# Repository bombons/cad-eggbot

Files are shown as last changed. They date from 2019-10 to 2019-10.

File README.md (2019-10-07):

# CAD

# Installazione

Per farlo funzionare serve OBBLIGATORIAMENTE il condensatore per disabilitare l'autoreset, condensatore da 10 µF posizionato su il pin RST GND; questo deve essere tolto ogni volta che si vuole reflashare la board

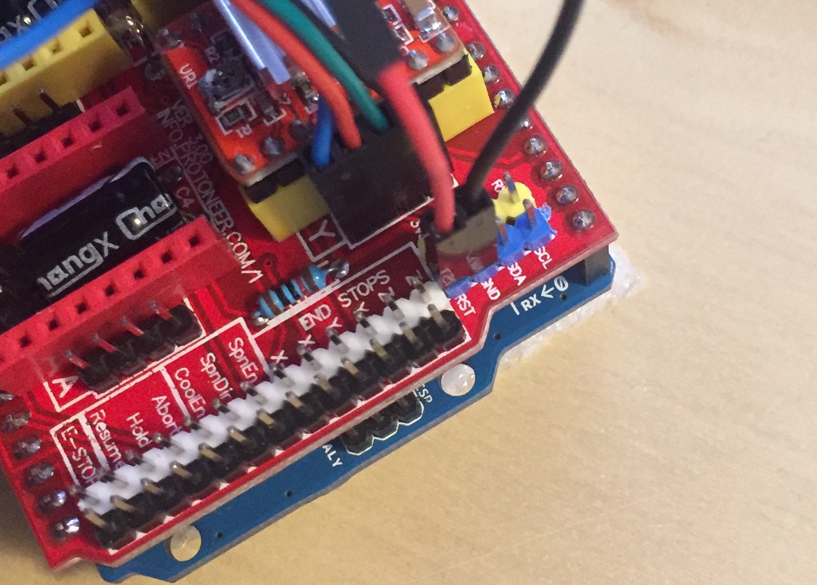
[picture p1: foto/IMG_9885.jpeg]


I motori girano giusti se mantengono questo ordine di fili dal basso verso l'alto (B)(R)(G)(BK)

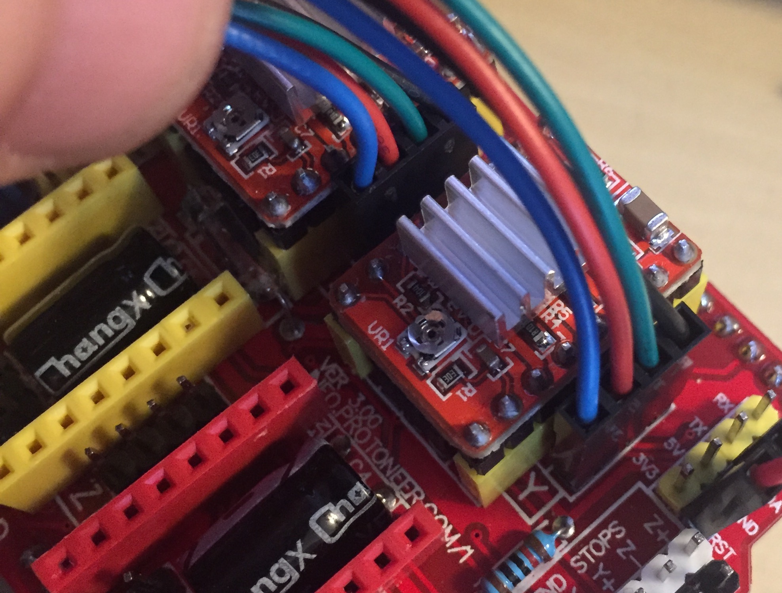
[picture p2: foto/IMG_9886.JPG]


Per il servo motore invece ho usato la posizione dei pin indicata nel firmware che è questa MARRONE->GND ROSSO->5V ARANCIO->Z.STEP

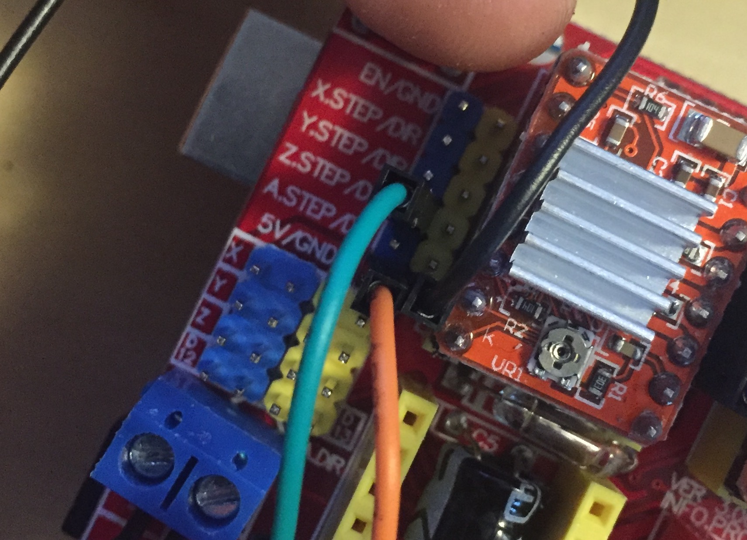
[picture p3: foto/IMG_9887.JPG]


# Firmware

Usata la fork di plex3r, volendo ha anche dei file da sostituire se il plugin su inkscape non funzionasse, però a me è andato senza problemi

[EggDuiono_plex3r](./firmware/EggDuino_plex3r)

# Estensione

Installa Inkscape

```bash
brew cask install InkScape
```

Poi installa l'estensione da [EggBot_v2.5.0_Mac.dmg](./firmware/EggBot_v2.5.0_Mac.dmg)

Dentro ci sono anche dei file di esempio

# TODO

<!-- - [x] per mettere il tik -->
- [ ] mettere switch per permettere di flashare senza togliere il condensatore
- [ ] ricontrolla come si calcola la VREF perchè cristian dice che quella spiegazione era un pochino errata ma in così per ora funzione ed è molto bassa
- [x] il cuscinetto sul filetto non si può vedere
- [x] migliorare il porta cuscinetto
- [x] soluzione più stabile del pezzo che porta la barra filettata
- [x] dove si inseriscono le barre metti delle viti per bloccare saldamente la barra
- [x] i fori stampati risultano leggermente troppo grandi in tutte le parti forse è un errore di stampa mio ma controlla sul file originale
- [x] al portapenna, cambia posizione del blocca penna e metti un pomellino

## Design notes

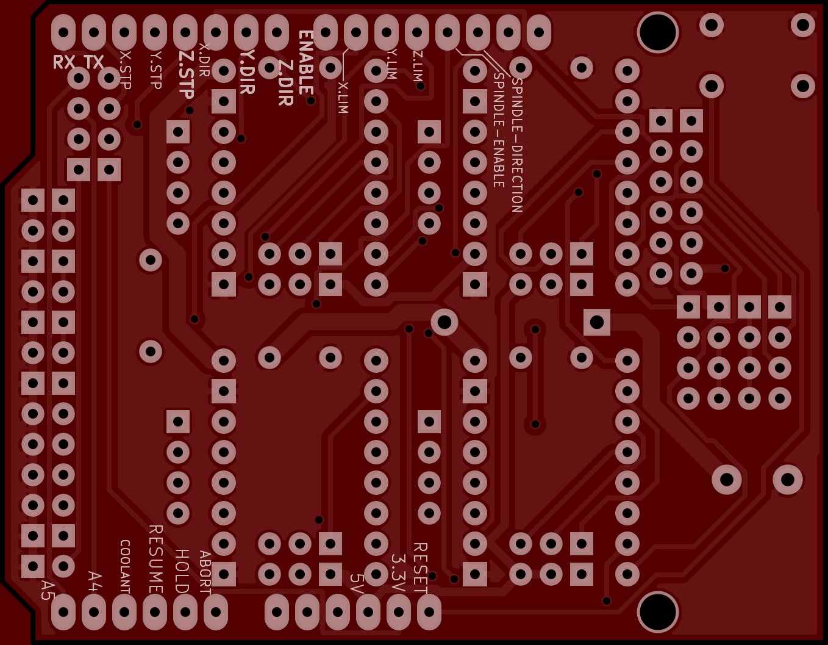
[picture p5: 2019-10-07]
progetto/035d4acb351dea535adb94660df1c265.png

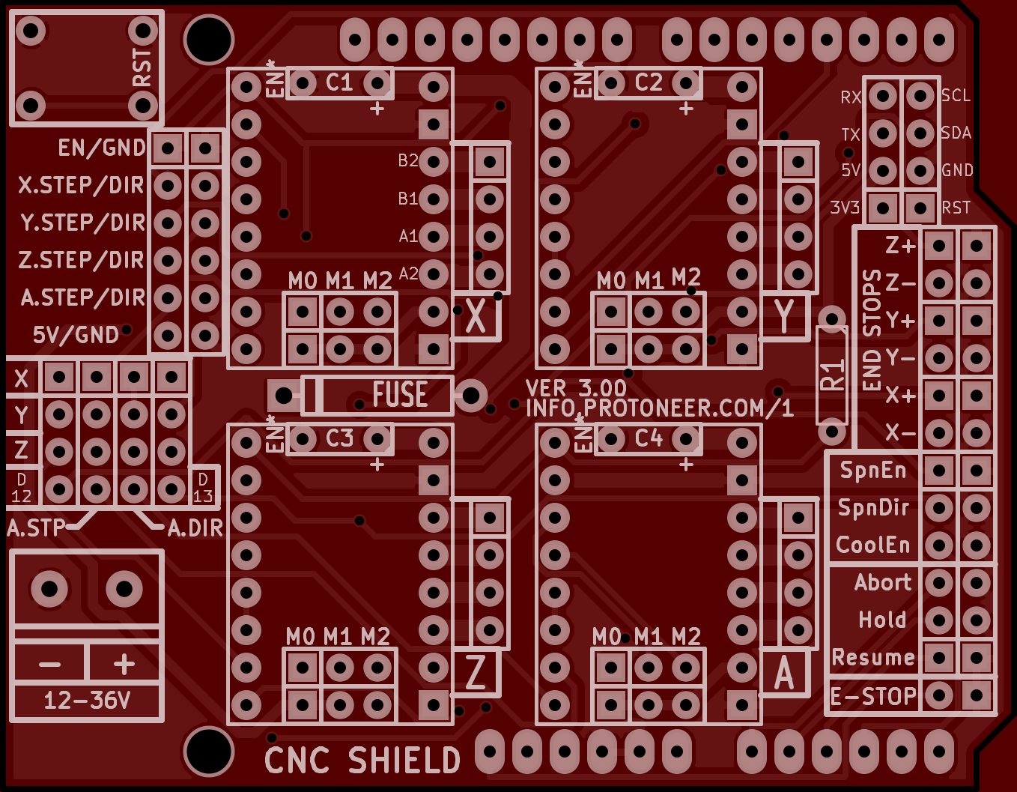
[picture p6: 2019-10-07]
progetto/sopra.png

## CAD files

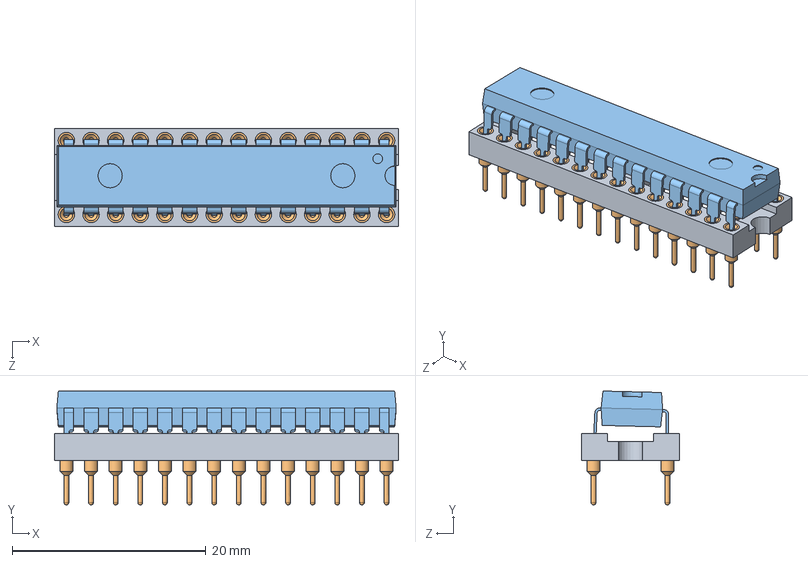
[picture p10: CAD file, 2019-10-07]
progetto/atmel.SLDASM
35.5 x 11.8 x 10.1 mm
porta_pin
socket_pin x 28
atmel

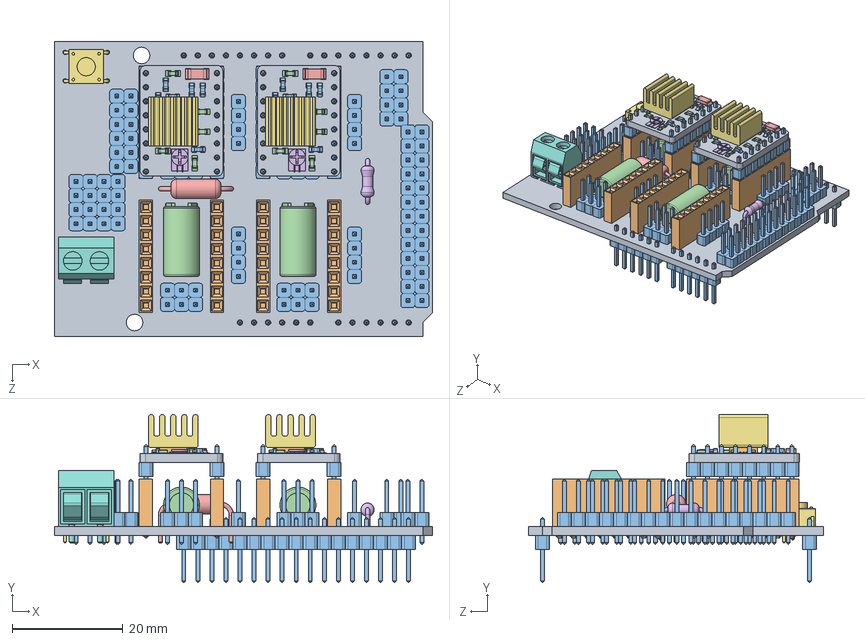
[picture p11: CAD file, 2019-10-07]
progetto/cnc_shield.SLDASM
68.3 x 30.4 x 53.3 mm
cnc_board
port x 8
pin x 30
condensatore x 4
fusibile
resistenza3
reset
alimentatore
board_A4988 x 2
microprocessore x 2
condensatore2 x 12
resistenza2 x 12
condensatore3 x 2
vref x 2
dissipatore x 2

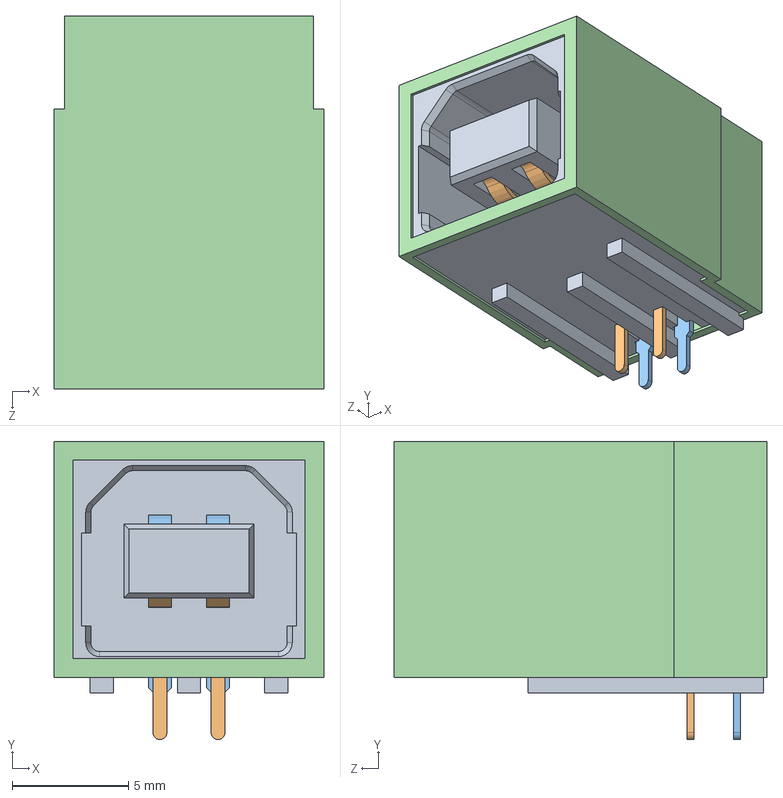
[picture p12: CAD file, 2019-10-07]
progetto/usb.SLDASM
11.6 x 12.8 x 16.0 mm
usb_corpo
usb_contatto_giu x 2
usb_contatto_su x 2
usb_shell

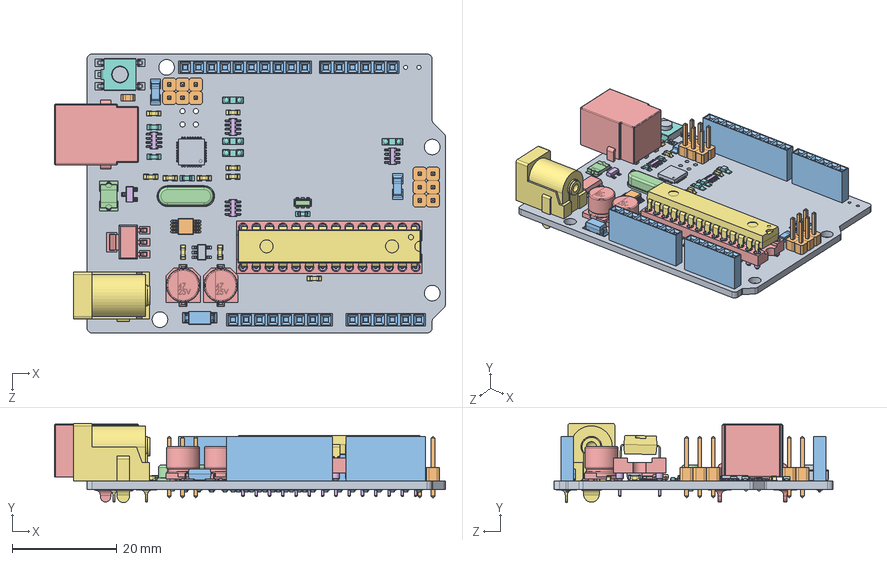
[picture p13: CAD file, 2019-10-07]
progetto/arduino_uno.SLDASM
74.8 x 15.2 x 53.3 mm
board
pin_header x 4
port_header x 4
16mhz_crystal
condensatore_47uf x 2
resistenza x 4
603_cap x 10
resistenza2 x 4
atmega16
blm
diodo x 2
crystal
porta_pin
socket_pin x 28
atmel
led x 4
lmv
lp2985
diodo2
mf
nano
ssot
jack_alimentazione
bottone_reset_copertura
bottone_reset_corpo
usb_corpo
usb_contatto_giu x 2
usb_contatto_su x 2
usb_shell

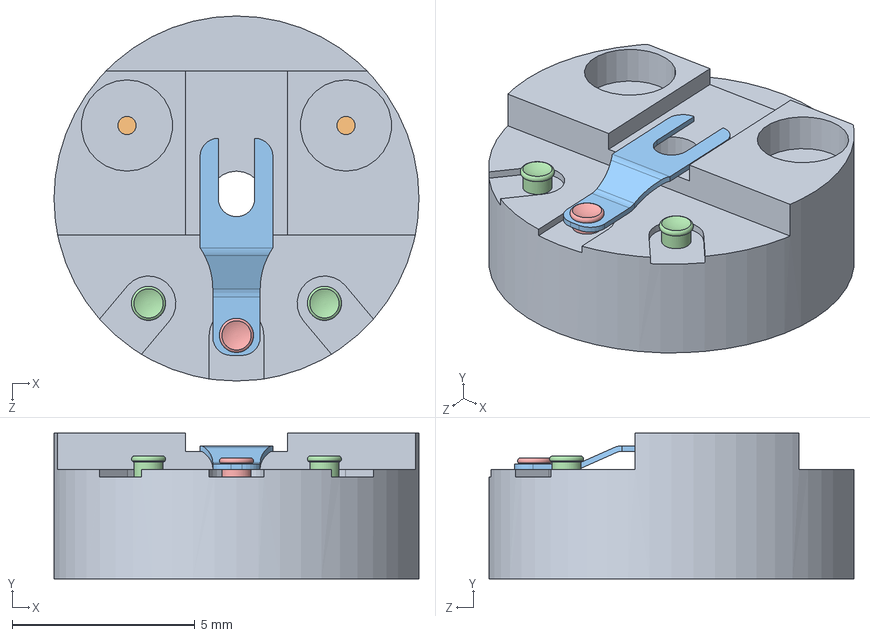
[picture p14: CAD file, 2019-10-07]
progetto/potenziometro_statore.SLDASM
10.0 x 4.00 x 10.0 mm
pot_corpo
pot_contatto_sotto
pot_piastra_contatto
pot_0.80mm x 2
pot_0.85mm

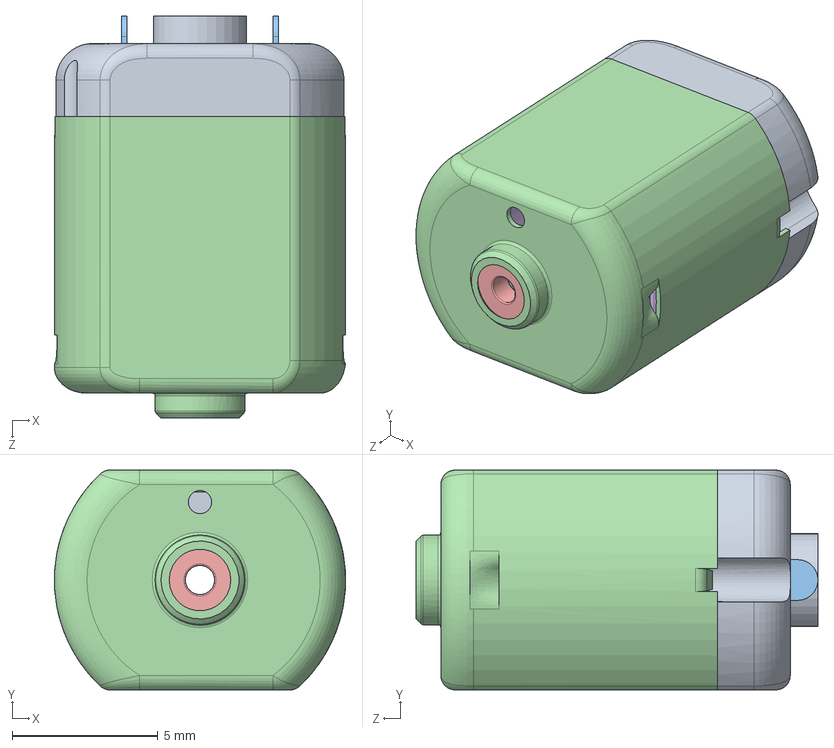
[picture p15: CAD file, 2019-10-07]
progetto/motore_statore.SLDASM
10.0 x 7.55 x 13.8 mm
statore_dietro
statore_cuscino2
statore_spazzole x 2
statore_davanti
statore_cuscino1
statore_magnete x 2
statore_molla

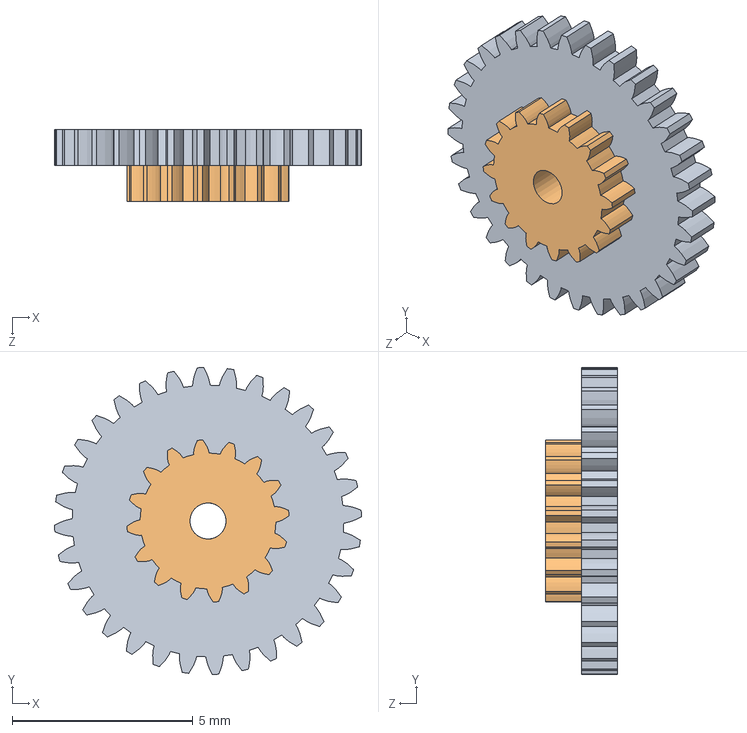
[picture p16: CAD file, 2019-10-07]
progetto/rot1.SLDASM
8.50 x 8.50 x 2.00 mm

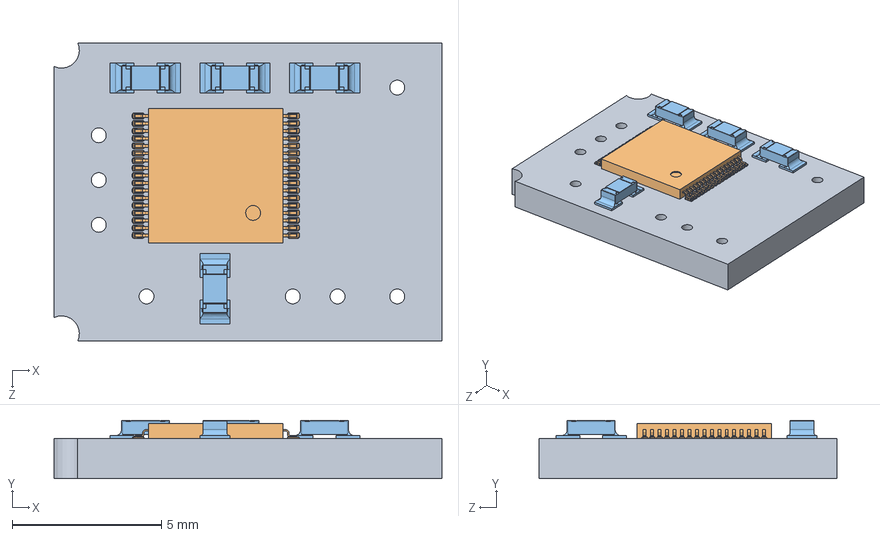
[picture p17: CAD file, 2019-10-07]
progetto/pcb.SLDASM
13.0 x 1.95 x 10.0 mm
pcb
pcb_microproc
pcb_resistenza x 4

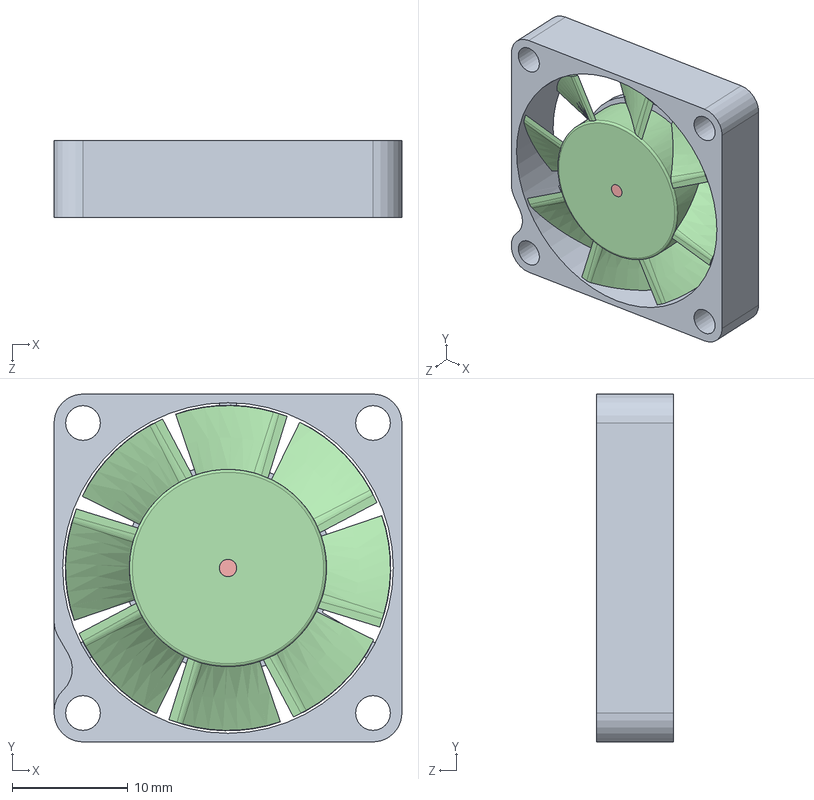
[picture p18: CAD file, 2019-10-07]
progetto/ventola.SLDASM
30.0 x 30.0 x 6.66 mm
telaio
armatura
magnete
paletta
asse
cuscino

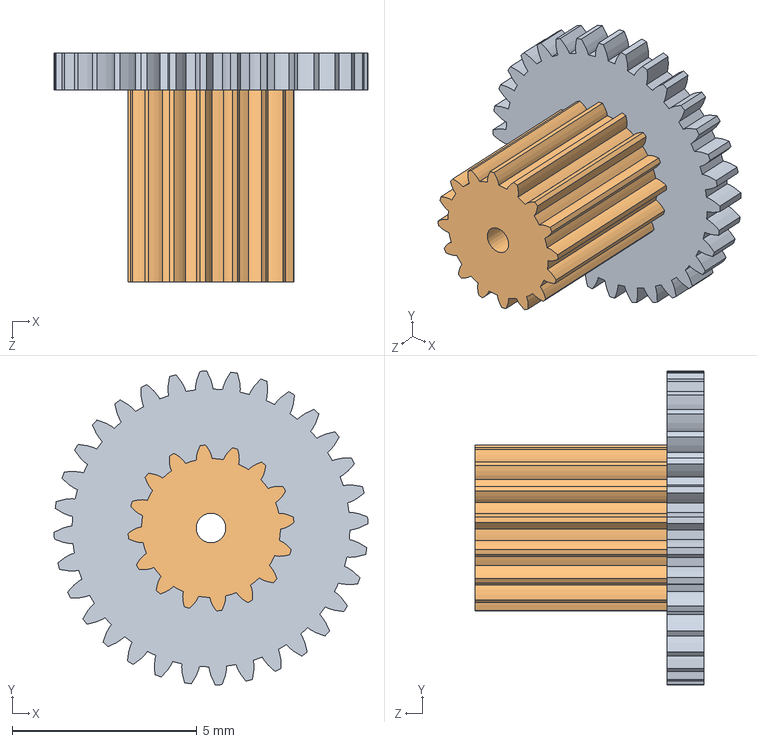
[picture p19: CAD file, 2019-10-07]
progetto/rot3.SLDASM
8.50 x 8.50 x 6.20 mm

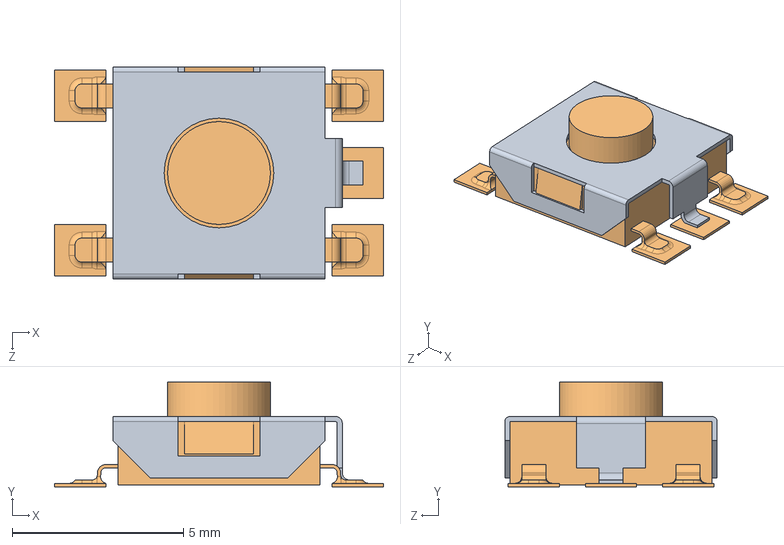
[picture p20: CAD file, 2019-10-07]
progetto/reset.SLDASM
9.60 x 3.05 x 6.20 mm
bottone_reset_copertura
bottone_reset_corpo

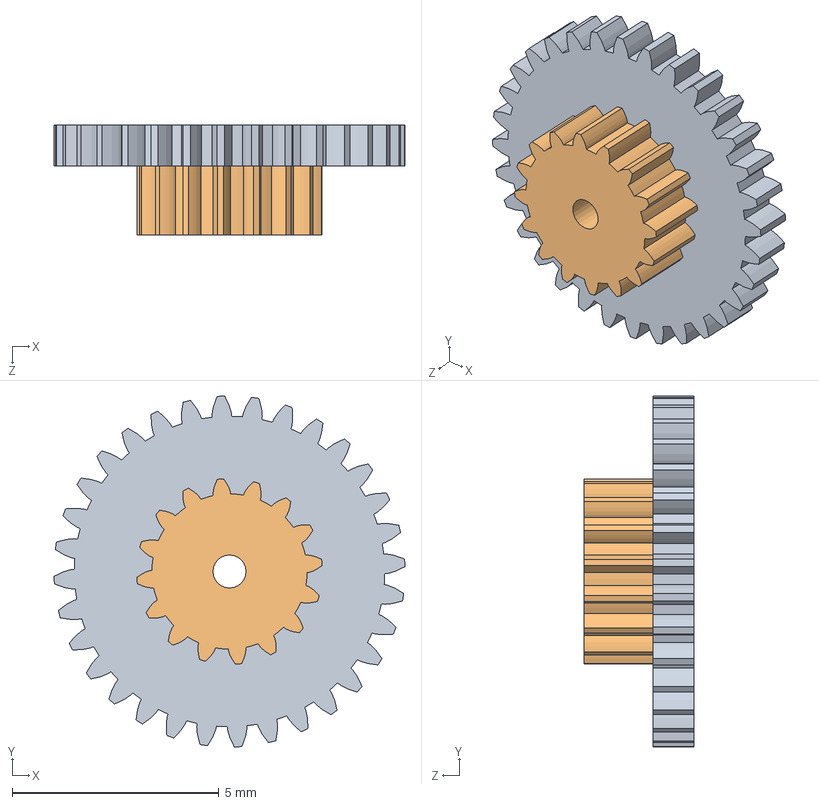
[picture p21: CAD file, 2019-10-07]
progetto/rot2.SLDASM
8.50 x 8.50 x 2.67 mm

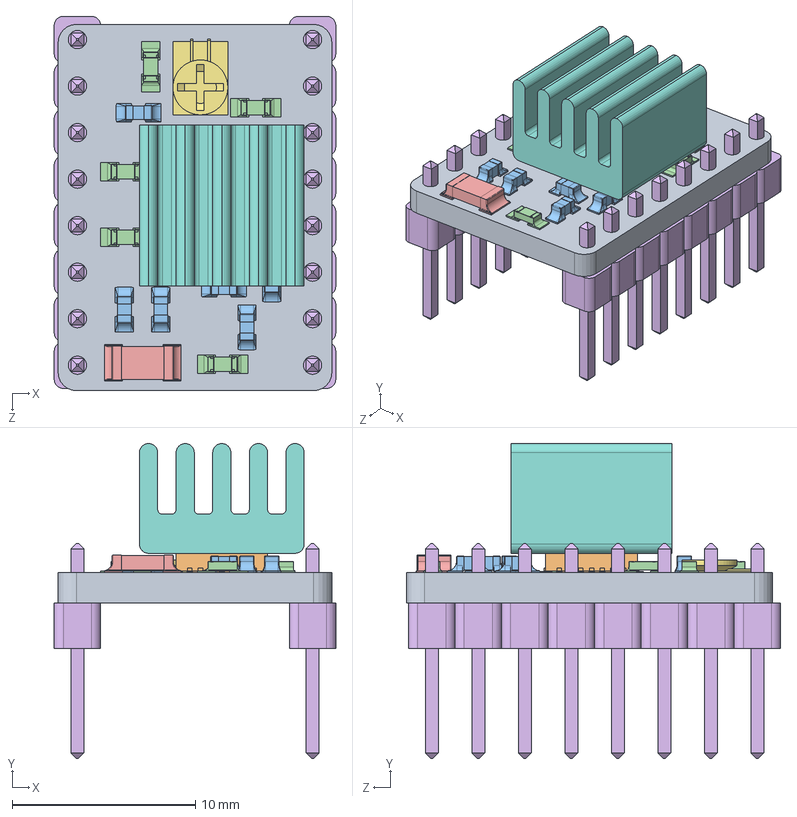
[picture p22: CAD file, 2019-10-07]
progetto/driver_A4988.SLDASM
15.4 x 17.2 x 20.4 mm
board_A4988
microprocessore
condensatore2 x 6
resistenza2 x 6
condensatore3
pin x 2
vref
dissipatore

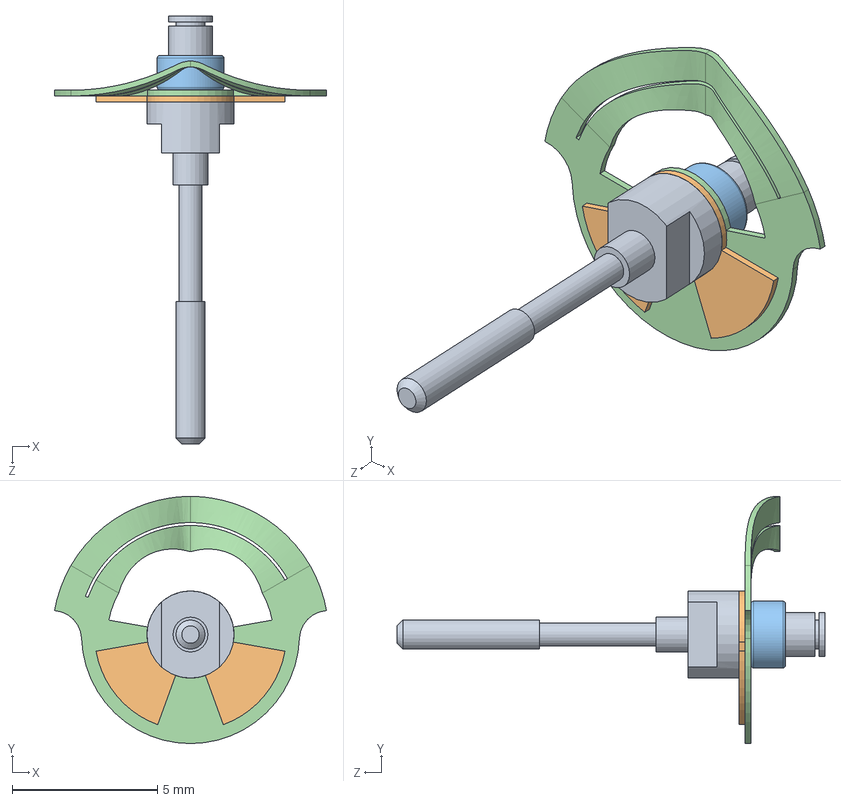
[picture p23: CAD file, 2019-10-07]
progetto/potenziometro_rotore.SLDASM
9.36 x 8.50 x 14.7 mm
pot_perno
pot_piastrina
pot_cuscino
pot_spazzole

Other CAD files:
progetto/6pin_header.SLDASM
progetto/statore_spazzole.SLDPRT
progetto/dietro.SLDPRT
progetto/pomello_barra_filettata.SLDPRT
progetto/1.1_32.SLDPRT
progetto/1.2_16.SLDPRT
progetto/1.3_32.SLDPRT
progetto/16mhz_crystal.SLDPRT
progetto/2.1_32.SLDPRT
progetto/2.2_16.SLDPRT
progetto/2.3_32.SLDPRT
progetto/2.4_16.SLDPRT
progetto/3.1_16.SLDPRT
progetto/603_cap.SLDPRT
progetto/SKF - 625 - 8,DE,AC,8_68.SLDPRT
progetto/alimentatore.SLDPRT
progetto/asse.SLDPRT
progetto/asse1.SLDPRT
progetto/asta_6mm.SLDDRW
progetto/asta_6mm.SLDPRT
progetto/atmega16.SLDPRT
progetto/atmel.SLDPRT
progetto/attacco.SLDPRT
progetto/barra_filettata.SLDPRT
progetto/blm.SLDPRT
progetto/board.SLDPRT
progetto/board_A4988.SLDPRT
progetto/bottone_reset_copertura.SLDPRT
progetto/bottone_reset_corpo.SLDPRT
progetto/cnc_board.SLDPRT
progetto/condensatore.SLDPRT
progetto/condensatore2.SLDPRT
progetto/condensatore3.SLDPRT
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

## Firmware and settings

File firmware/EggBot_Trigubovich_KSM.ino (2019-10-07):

/* Eggduino-Firmware by Joachim Cerny, 2014

   Thanks for the nice libs ACCELSTEPPER and SERIALCOMMAND, which made this project much easier.
   Thanks to the Eggbot-Team for such a funny and enjoable concept!
   Thanks to my wife and my daughter for their patience. :-)

 */

// implemented Eggbot-Protocol-Version v13
// EBB-Command-Reference, I sourced from: http://www.schmalzhaus.com/EBB/EBBCommands.html
// no homing sequence, switch-on position of pen will be taken as reference point.
// No collision-detection!!
// Supported Servos: I do not know, I use Arduino Servo Lib with TG9e- standard servo.
// Note: Maximum-Speed in Inkscape is 1000 Steps/s. You could enter more, but then Pythonscript sends nonsense.
// EBB-Coordinates are coming in for 16th-Microstepmode. The Coordinate-Transforms are done in weired integer-math. Be careful, when you diecide to modify settings.

/* TODOs:
   1	collision control via penMin/penMax
   2	implement homing sequence via microswitch or optical device
 */

#include "AccelStepper.h" // nice lib from http://www.airspayce.com/mikem/arduino/AccelStepper/
#include "VarSpeedServo.h" // variable speed servo lib https://github.com/netlabtoolkit/VarSpeedServo
#include "SerialCommand.h" //nice lib from Stefan Rado, https://github.com/kroimon/Arduino-SerialCommand
#include <avr/eeprom.h>
#include "button.h"


#define initSting "EBBv13_and_above Protocol emulated by Eggduino-Firmware V1.x"

//#define BOARD_ULN2003
#define BOARD_ZAGGO
//#define BOARD_CNCSHIELD

#ifdef BOARD_ULN2003
	// Mini Spherebot using 28BYJ-48 Steppers with ULN2003 Drivers
	// http://www.thingiverse.com/thing:1461709
	#define rotMicrostep 16
	#define penMicrostep 16
	#define servoPin 13
	#define engraverPin 12
	
	// These values work for my 28BYJ-48's, Your's might 
	// be different and may need adjustment.
	
	#define penStepsPerRev 4096
	#define rotStepsUseable 1100
	
	//Buttons (uncomment to enable)
	//#define prgButton 2 // PRG button
	//#define penToggleButton 12 // pen up/down button
	//#define motorsButton 4 // motors enable button
#endif

#ifdef BOARD_ZAGGO
	//Zaggo SphereBot design: http://pleasantsoftware.com/developer/3d/spherebot/
	//Rotational Stepper:
	#define step1 11
	#define dir1 10
	#define enableRotMotor 9
	#define rotMicrostep 16  //MicrostepMode, only 1,2,4,8,16 allowed, because of Integer-Math in this Sketch
	//Pen Stepper:
	#define step2 6
	#define dir2 5
	#define enablePenMotor 4
	#define penMicrostep 16 //MicrostepMode, only 1,2,4,8,16 allowed, because of Integer-Math in this Sketch
	//Servo
	#define servoPin 8
	#define engraverPin 7
	//Buttons (uncomment to enable)
	//#define prgButton 2 // PRG button
	#define penToggleButton 12 // pen up/down button
	//#define motorsButton 3
	// motors enable button
#endif

#ifdef BOARD_CNCSHIELD
	//CNC Shield: http://blog.protoneer.co.nz/arduino-cnc-shield/
	//Rotational Stepper: ("X")
	#define step1 2
	#define dir1 5
	#define enableRotMotor 8
	#define rotMicrostep 16  //MicrostepMode, only 1,2,4,8,16 allowed, because of Integer-Math in this Sketch
	//Pen Stepper:        ("Y")
	#define step2 3
	#define dir2 6
	#define enablePenMotor 8
	#define penMicrostep 16 //MicrostepMode, only 1,2,4,8,16 allowed, because of Integer-Math in this Sketch
	//Servo
	#define servoPin 12          // "SpnEn"
	#define engraverPin 13       // "SpnDir"
	//Buttons
	#define prgButton A0         // PRG button ("Abort")
	#define penToggleButton A1   // pen up/down button ("Hold")
	#define motorsButton A2      // motors enable button ("Resume")
#endif


//-----------------------------------------------------------------------------------------------------------


#define penUpPosEEAddress ((uint16_t *)0)
#define penDownPosEEAddress ((uint16_t *)2)
#define penUpRateEEAddress ((uint16_t *)4)
#define penDownRateEEAddress ((uint16_t *)6)

void setprgButtonState();
void doTogglePen();
void toggleMotors();
void makeComInterface();
void initHardware();
void moveOneStep();

//make Objects
#ifdef BOARD_ULN2003
AccelStepper rotMotor(AccelStepper::HALF4WIRE, 2,4,3,5, true);
AccelStepper penMotor(AccelStepper::HALF4WIRE, 8,10,9,11, true);
#else
AccelStepper rotMotor(1, step1, dir1);
AccelStepper penMotor(1, step2, dir2);
#endif

VarSpeedServo penServo;
SerialCommand SCmd;
//create Buttons
#ifdef prgButton
	Button prgButtonToggle(prgButton, setprgButtonState);
#endif
#ifdef penToggleButton
	Button penToggle(penToggleButton, doTogglePen);
#endif
#ifdef motorsButton
	Button motorsToggle(motorsButton, toggleMotors);
#endif
// Variables... be careful, by messing around here, everything has a reason and crossrelations...
int penMin=0;
int penMax=0;
int penUpPos=5;  //can be overwritten from EBB-Command SC
int penDownPos=20; //can be overwritten from EBB-Command SC
int servoRateUp=0;
int servoRateDown=0;
long rotStepError=0;
long penStepError=0;
int penState=penUpPos;
uint32_t nodeCount=0;
unsigned int layer=0;
boolean prgButtonState=0;
uint8_t rotStepCorrection = 16/rotMicrostep ; //devide EBB-Coordinates by this factor to get EGGduino-Steps
uint8_t penStepCorrection = 16/penMicrostep ; //devide EBB-Coordinates by this factor to get EGGduino-Steps
float rotSpeed=0;
float penSpeed=0; // these are local variables for Function SteppermotorMove-Command, but for performance-reasons it will be initialized here
boolean motorsEnabled = 0;

void setup() {   
	Serial.begin(9600);
	makeComInterface();
	initHardware();
}

void loop() {
	moveOneStep();

	SCmd.readSerial();

#ifdef penToggleButton
	penToggle.check();
#endif

#ifdef motorsButton
	motorsToggle.check();
#endif

#ifdef prgButton
	prgButtonToggle.check();
#endif
}

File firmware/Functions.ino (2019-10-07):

void makeComInterface(){
	SCmd.addCommand("v",sendVersion);
	SCmd.addCommand("EM",enableMotors);
	SCmd.addCommand("SC",stepperModeConfigure);
	SCmd.addCommand("SP",setPen);
	SCmd.addCommand("SM",stepperMove);
	SCmd.addCommand("SE",setEngraver);
	SCmd.addCommand("TP",togglePen);
	SCmd.addCommand("PD",ignore);
	SCmd.addCommand("PO",pinOutput);
	SCmd.addCommand("NI",nodeCountIncrement);
	SCmd.addCommand("ND",nodeCountDecrement);
	SCmd.addCommand("SN",setNodeCount);
	SCmd.addCommand("QN",queryNodeCount);
	SCmd.addCommand("SL",setLayer);
	SCmd.addCommand("QL",queryLayer);
	SCmd.addCommand("QP",queryPen);
	SCmd.addCommand("QB",queryButton);  //"PRG" Button,
	SCmd.setDefaultHandler(unrecognized); // Handler for command that isn't matched (says "What?")
}

void queryPen() {
	char state;
	if (penState==penUpPos)
		state='0';
	else
		state='1';
	Serial.print(String(state)+"\r\n");
	sendAck();
}

void queryButton() {
	Serial.print(String(prgButtonState) +"\r\n");
	sendAck();
	prgButtonState = 0;
}

void queryLayer() {
	Serial.print(String(layer) +"\r\n");
	sendAck();
} 

void setLayer() {
	uint32_t value=0;
	char *arg1;
	arg1 = SCmd.next();
	if (arg1 != NULL) {
		value = atoi(arg1);
		layer=value;
		sendAck();
	}
	else
		sendError();
}

void queryNodeCount() {
	Serial.print(String(nodeCount) +"\r\n");
	sendAck();

}

void setNodeCount() {
	uint32_t value=0;
	char *arg1;
	arg1 = SCmd.next();
	if (arg1 != NULL) {
		value = atoi(arg1);
		nodeCount=value;
		sendAck();
	}
	else
		sendError();
}

void nodeCountIncrement() {
	nodeCount=nodeCount++;
	sendAck();	
}

void nodeCountDecrement() {
	nodeCount=nodeCount--;
	sendAck();
}

void stepperMove() {
	uint16_t duration=0; //in ms
	int penStepsEBB=0; //Pen
	int rotStepsEBB=0; //Rot

	moveToDestination();

	if (!parseSMArgs(&duration, &penStepsEBB, &rotStepsEBB)) {
		sendError();
		return;
	}

	sendAck();

	if ( (penStepsEBB==0) && (rotStepsEBB==0) ) {
		delay(duration);
		return;
	}

	prepareMove(duration, penStepsEBB, rotStepsEBB);
}


void setPenUp() {
	penServo.write(penUpPos, servoRateUp, true);
	penState=penUpPos;
}


void setPenDown() {
	penServo.write(penDownPos, servoRateDown, true);
	penState=penDownPos;
}


void setPen(){
	int cmd;
	int value;
	char *arg;

	moveToDestination();

	arg = SCmd.next();
	if (arg != NULL) {
		cmd = atoi(arg);
		switch (cmd) {
			case 0:
        sendAck();
				setPenDown();
				break;

			case 1:
        sendAck();
				setPenUp();        
				break;

			default:
				sendError();
		}
	}
	char *val;
	val = SCmd.next();
	if (val != NULL) {
		value = atoi(val);
		delay(value);
	}
}  

void togglePen(){
	int value;
	char *arg;

	moveToDestination();

	arg = SCmd.next();
	if (arg != NULL)
		value = atoi(arg);
	else
		value = 500;

	doTogglePen();
	sendAck();
	delay(value);
}

void doTogglePen() {
	if (penState==penUpPos) {
		setPenDown();
	} else   {
		setPenUp();
	}
}

void enableMotors(){
	int cmd;
	int value;
	char *arg;
	char *val;
	arg = SCmd.next();
	if (arg != NULL)
		cmd = atoi(arg);
	val = SCmd.next();
	if (val != NULL)
		value = atoi(val);
	//values parsed
	if ((arg != NULL) && (val == NULL)){
		switch (cmd) {
			case 0: motorsOff();
				sendAck();
				break;
			case 1: motorsOn();
				sendAck();
				break;
			default:
				sendError();
		}
	}
	//the following implementaion is a little bit cheated, because i did not know, how to implement different values for first and second argument.
	if ((arg != NULL) && (val != NULL)){
		switch (value) {
			case 0: motorsOff();
				sendAck();
				break;
			case 1: motorsOn();
				sendAck();
				break;
			default:
				sendError();
		}
	}
}

void stepperModeConfigure(){
	int cmd;
	int value;
	char *arg;
	arg = SCmd.next();
	if (arg != NULL)
		cmd = atoi(arg);
	char *val;
	val = SCmd.next();
	if (val != NULL)
		value = atoi(val);
	if ((arg != NULL) && (val != NULL)){
		switch (cmd) {
			case 4: penUpPos= (int) ((float) (value-6000)/(float) 133.3); // transformation from EBB to PWM-Servo
				storePenUpPosInEE();
				sendAck();
				break;
			case 5: penDownPos= (int)((float) (value-6000)/(float) 133.3); // transformation from EBB to PWM-Servo
				storePenDownPosInEE();
				sendAck();
				break;
			case 6: //rotMin=value;    ignored
				sendAck();
				break;
			case 7: //rotMax=value;    ignored
				sendAck();
				break;
			case 11: servoRateUp=value / 5;
        eeprom_update_word(penUpRateEEAddress, servoRateUp);
				sendAck();
				break;
			case 12: servoRateDown=value / 5;
			  eeprom_update_word(penDownRateEEAddress, servoRateDown);     
				sendAck();
				break;
			default:
				 sendError();
		}
	}
}

void pinOutput(){
	char *arg1;
	char *arg2;
	char *arg3;
	int val;

	arg1 = SCmd.next();
	arg2 = SCmd.next();
	arg3 = SCmd.next();
	if (arg1 == NULL || arg2 == NULL || arg3 == NULL) {
		sendError();
		return;
	}
	//PO,B,3,0 = disable engraver
	//PO,B,3,1 = enable engraver
	if (arg1[0] == 'B' && arg2[0] == '3') {
		val = atoi(arg3);
		digitalWrite(engraverPin, val);
	}
	sendAck();
}

//currently inkscape extension is using PO command for engraver instead of SE
void setEngraver(){
	char *arg;
	int val;
	arg = SCmd.next();
	if (arg != NULL) {
		val = atoi(arg);
		digitalWrite(engraverPin, val);
	}
	sendAck();
}

void sendVersion(){
	Serial.print(initSting);
	Serial.print("\r\n");
}

void unrecognized(const char *command){
	sendError();
}

void ignore(){
	sendAck();
}
